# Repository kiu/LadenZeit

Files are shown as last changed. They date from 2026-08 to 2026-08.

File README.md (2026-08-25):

# LadenZeit
LadenZeit - Never miss opening hours again. Minimalist OLED store tracker with rotary control

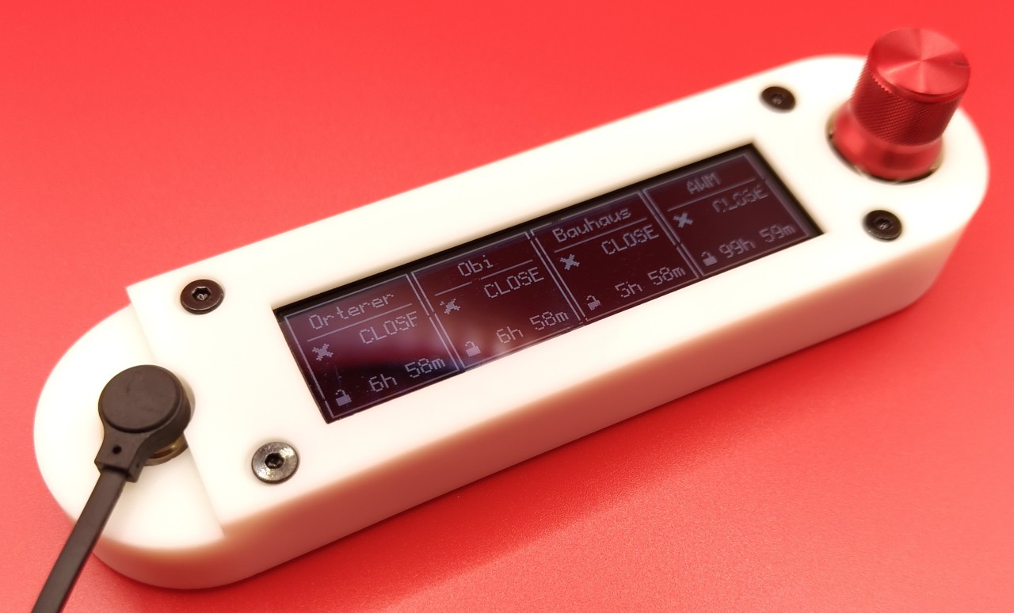
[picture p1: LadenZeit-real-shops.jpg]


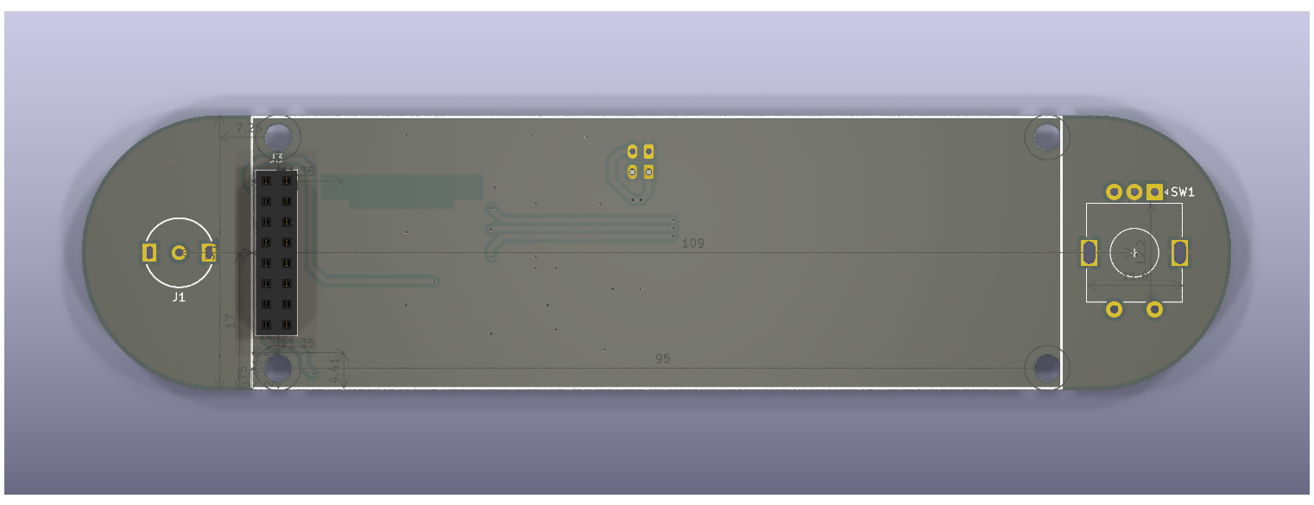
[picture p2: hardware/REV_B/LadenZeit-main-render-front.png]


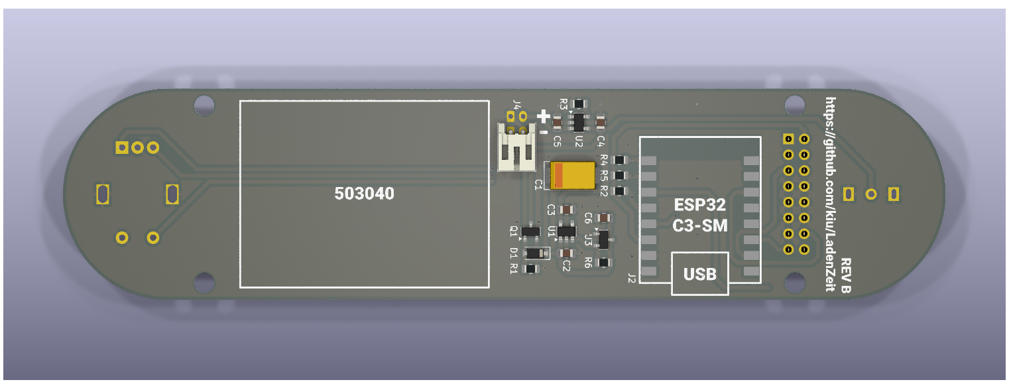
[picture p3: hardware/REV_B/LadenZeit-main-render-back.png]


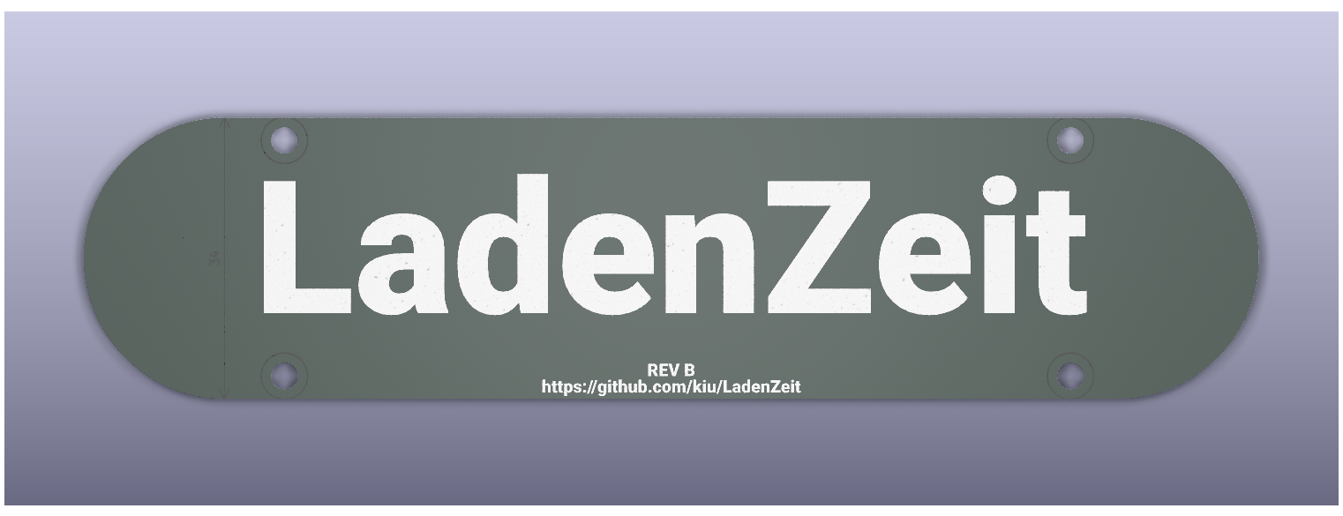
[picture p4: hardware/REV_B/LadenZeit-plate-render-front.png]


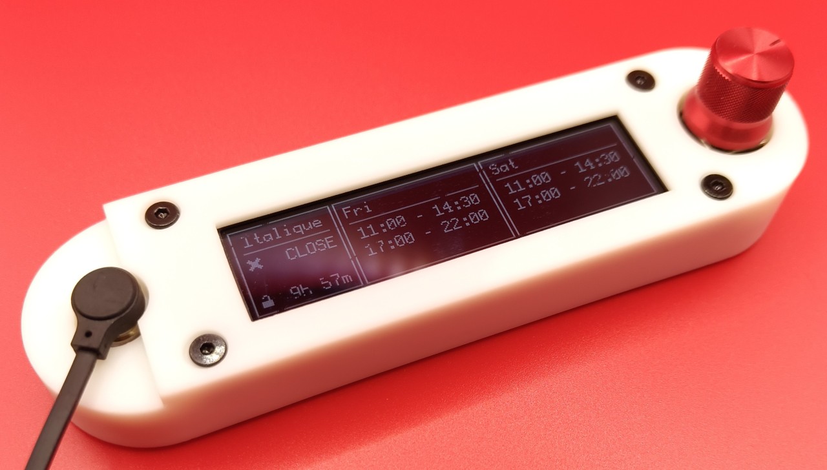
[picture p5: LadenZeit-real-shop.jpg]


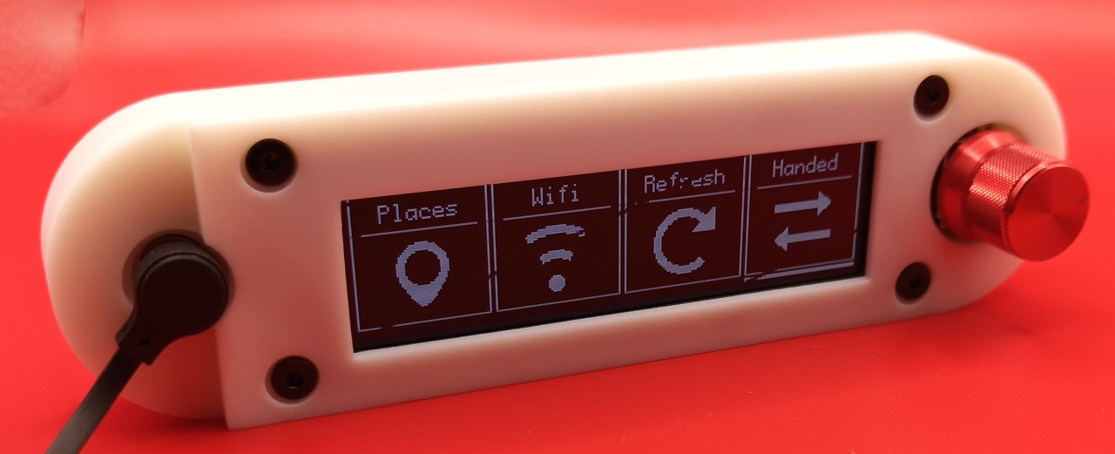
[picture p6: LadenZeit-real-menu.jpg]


## Device

- [main](hardware/REV_B/main/): The main PCB
- [plate](hardware/REV_B/plate/): PCB used as backplate
- [mech](hardware/REV_B/mech/): OpenSCAD case
- [BOM](hardware/REV_B/LadenZeit-bom.pdf): Bill of materials

### Firmware (Arduino IDE)

- [source](firmware/LadenZeit/)
- [UI flow](firmware/ladenzeit-ui-flow.drawio.png)

Arduino IDE config
- Board: [ESP32C3 Dev Module](https://github.com/espressif/arduino-esp32)
- Library: [U8g2](https://github.com/olikraus/u8g2)
- Library: [ESP32Time](https://github.com/fbiego/ESP32Time)
- Config: "USB CDC On Boot: Enabled"
- Config: "CPU Frequency: 80MHz (WiFi)"
- Config: "Partition Scheme: Huge APP (3MB No OTA/1MB SPIFFFS)"

## Server (Java Spring Boot)

- [source](server/LadenZeitServer)
- [single file frontend](server/index.html)
- [service](server/ladenzeit.service)

Inject Google Maps API key via environment.

# License
This project is licensed under the Creative Commons Attribution-NonCommercial 3.0 Unported (CC BY-NC 3.0) license.

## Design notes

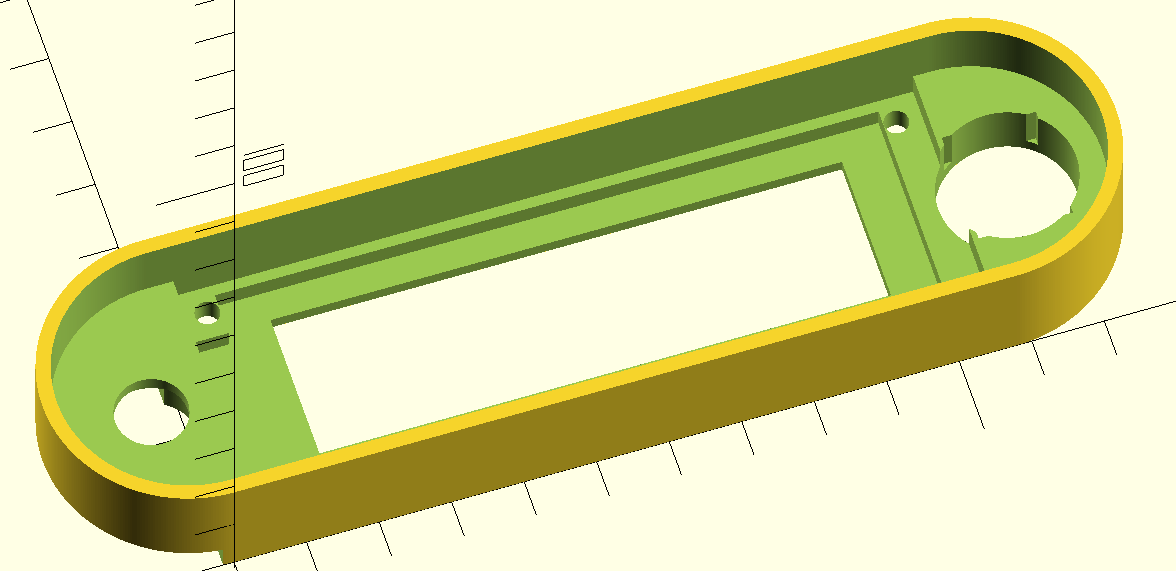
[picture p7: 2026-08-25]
hardware/REV_B/LadenZeit-mech-render.png

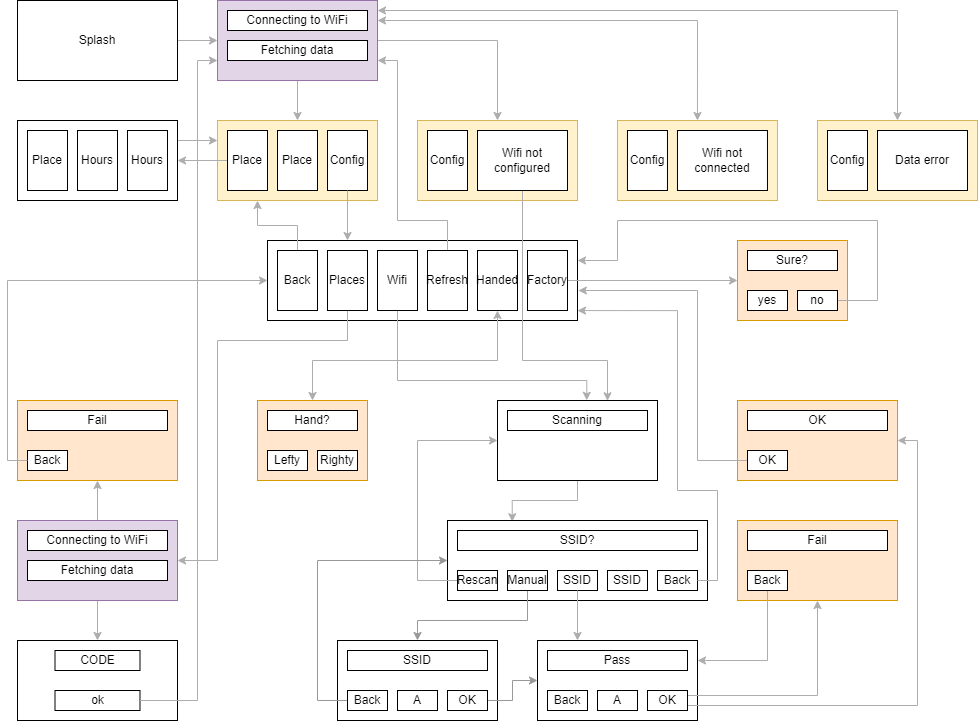
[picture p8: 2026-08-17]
firmware/ladenzeit-ui-flow.drawio.png

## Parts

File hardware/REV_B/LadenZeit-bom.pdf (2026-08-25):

BOM-PCBA

Page 1

Designator | Description | Req | Price | Price (sum) | Provider | ID
MOQ 10
U1 | XC6220B331MR-G | 1 | 0,3579 € | 0,3579 € | | C86534
U2 | MCP73831T-2ACI/OT | 1 | 0,7113 € | 0,7113 € | | C424093
U3 | APX803L-34SA-7 | 1 | 0,1379 € | 0,1379 € | | C2067862
D1 | B5819W SL | 1 | 0,0270 € | 0,0270 € | | C8598
Q1 | DMG2301L-7 | 1 | 0,1080 € | 0,1080 € | | C102619
SW1 | PEC11R-4215F-S0024 | 1 | 1,7730 € | 1,7730 € | | C143790
J1 | USB MG0175 | 1 | 4,9345 € | 4,9345 € | de.aliexpress.com | 1005011921156462
J2 | ESP32-C3 Super Mini | 1 | 2,6590 € | 2,6590 € | de.aliexpress.com | 1005008809016984
J3 | OLED 3.12” 256*64 | 1 | 12,7900 € | 12,7900 € | de.aliexpress.com | 1005003091450549
J4 | B2B-PH-K-S(LF)(SN) | 1 | 0,0317 € | 0,0317 € | | C131337
R1, R3 | 10k 0805 | 2 | 0,0028 € | 0,0056 € | | C2930231
R2, R4, R5, R6 | 47k 0805 | 4 | 0,0095 € | 0,0380 € | | C17713
C1 | 100uF 16V CASE-E-7343 | 1 | 0,5897 € | 0,5897 € | | C554014
C2, C4, C5 | 4.7uF 25V 0805 | 3 | 0,0392 € | 0,1176 € | | C1779
C3 | 47uF 10V 0805 | 1 | 0,1432 € | 0,1432 € | | C19103846
C6 | 100nF 0805 | 1 | 0,0194 € | 0,0194 € | | C49678
- | Dial D-Shaped 15/17*16 | 1 | 1,5250 € | 1,5250 € | de.aliexpress.com | 1005005746658381
- | Li-Ion 503040 | 1 | 4,8750 € | 4,8750 € | de.aliexpress.com | 1005009778420830
- | M3x12 hex screw (ultra flat) | 4 | 0,0430 € | 0,1720 € | de.aliexpress.com | 1005008305312481
- | | 4 | 0,0318 € | 0,1272 € | de.aliexpress.com | 1005008305312481
- | M3x7 spacer | 4 | 0,1590 € | 0,6360 € | de.aliexpress.com | 1005009383384524
- | M3x3 spacer | 4 | 0,0184 € | 0,0736 € | de.aliexpress.com | 1005004322149134

SUM
31,85 €
318,53 €

www.lcsc.com
www.lcsc.com
www.lcsc.com
www.lcsc.com
www.lcsc.com
www.lcsc.com

www.lcsc.com
www.lcsc.com
www.lcsc.com
www.lcsc.com
www.lcsc.com
www.lcsc.com
www.lcsc.com

M3x4 hex screw (ultra flat)

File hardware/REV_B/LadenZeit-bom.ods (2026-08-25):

Designator | Description | Req | Price | Price (sum) | Provider | ID
 |  |  | MOQ | 10
U1 | XC6220B331MR-G | 1 | 0,3579 € | 0,3579 € | www.lcsc.com | C86534
U2 | MCP73831T-2ACI/OT | 1 | 0,7113 € | 0,7113 € | www.lcsc.com | C424093
U3 | APX803L-34SA-7 | 1 | 0,1379 € | 0,1379 € | www.lcsc.com | C2067862
D1 | B5819W SL | 1 | 0,0270 € | 0,0270 € | www.lcsc.com | C8598
Q1 | DMG2301L-7 | 1 | 0,1080 € | 0,1080 € | www.lcsc.com | C102619
SW1 | PEC11R-4215F-S0024 | 1 | 1,7730 € | 1,7730 € | www.lcsc.com | C143790
J1 | USB MG0175 | 1 | 4,9345 € | 4,9345 € | de.aliexpress.com | 1005011921156462
J2 | ESP32-C3 Super Mini | 1 | 2,6590 € | 2,6590 € | de.aliexpress.com | 1005008809016984
J3 | OLED 3.12” 256*64 | 1 | 12,7900 € | 12,7900 € | de.aliexpress.com | 1005003091450549
J4 | B2B-PH-K-S(LF)(SN) | 1 | 0,0317 € | 0,0317 € | www.lcsc.com | C131337
R1, R3 | 10k 0805 | 2 | 0,0028 € | 0,0056 € | www.lcsc.com | C2930231
R2, R4, R5, R6 | 47k 0805 | 4 | 0,0095 € | 0,0380 € | www.lcsc.com | C17713
C1 | 100uF 16V CASE-E-7343 | 1 | 0,5897 € | 0,5897 € | www.lcsc.com | C554014
C2, C4, C5 | 4.7uF 25V 0805 | 3 | 0,0392 € | 0,1176 € | www.lcsc.com | C1779
C3 | 47uF 10V 0805 | 1 | 0,1432 € | 0,1432 € | www.lcsc.com | C19103846
C6 | 100nF 0805 | 1 | 0,0194 € | 0,0194 € | www.lcsc.com | C49678
- | Dial D-Shaped 15/17*16 | 1 | 1,5250 € | 1,5250 € | de.aliexpress.com | 1005005746658381
- | Li-Ion 503040 | 1 | 4,8750 € | 4,8750 € | de.aliexpress.com | 1005009778420830
- | M3x12 hex screw (ultra flat) | 4 | 0,0430 € | 0,1720 € | de.aliexpress.com | 1005008305312481
- | M3x4 hex screw (ultra flat) | 4 | 0,0318 € | 0,1272 € | de.aliexpress.com | 1005008305312481
- | M3x7 spacer | 4 | 0,1590 € | 0,6360 € | de.aliexpress.com | 1005009383384524
- | M3x3 spacer | 4 | 0,0184 € | 0,0736 € | de.aliexpress.com | 1005004322149134
 |  |  |  | SUM
 |  |  |  | 31,85 €
 |  |  |  | 318,53 €

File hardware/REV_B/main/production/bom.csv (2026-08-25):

Designator | Footprint | Quantity | Value | LCSC Part #
C1 | CP_EIA-7343-43_Kemet-X_HandSolder | 1 | 100uF | C554014
C2, C4, C5 | 0805 | 3 | 4.7uF | C1779
C3 | 0805 | 1 | 47uF | C19103846
C6 | 0805 | 1 | 100nF | C49678
D1 | D_SOD-123 | 1 | D_Schottky | C8598
J1 | USB MG0175M | 1 | Conn_01x02
J2 | ESP32-C3-SM-SMT | 1 | Conn_02x08_Odd_Even
J3 | PinSocket_2x08_P2.54mm_Vertical | 1 | Conn_02x08_Odd_Even | C30734
J4 | JST_PH_S2B-PH-K_1x02_P2.00mm_Horizontal-Multi | 1 | Conn_01x02 | C131337
Q1 | SOT-23 | 1 | DMG2301L | C102619
R1, R3 | 0805 | 2 | 10k | C2930231
R2, R4, R5, R6 | 0805 | 4 | 47k | C17713
SW1 | RotaryEncoder_Alps_EC11E-Switch_Vertical_H20mm | 1 | RotaryEncoder | C143790
U1 | SOT-23-5 | 1 | XC6220B331MR | C86534
U2 | SOT-23-5 | 1 | MCP73831-2-OT | C424093
U3 | SOT-23 | 1 | APX803L | C2067862

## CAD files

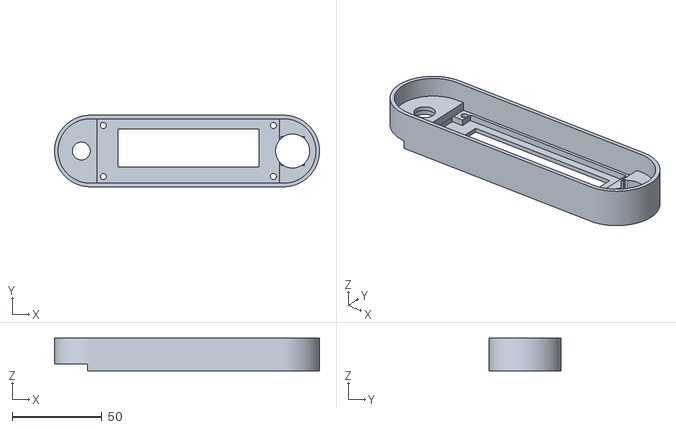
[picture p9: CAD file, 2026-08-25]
hardware/REV_B/mech/LadenZeit.stl
148.0 x 40.0 x 18.4

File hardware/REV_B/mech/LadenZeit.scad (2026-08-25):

$fn = $preview?20:360;
//$fn = $preview?20:60;

pcb_thick = 1;

pcb_width = 108;
pcb_height = 34;

pcb_oled_width = 100;
pcb_oled_height = 33.5;

pcb_oled_spacing = 3;

oled_screen_width = 78.8;
oled_screen_height = 21.18;
oled_screen_thick = 2.8;

oled_screen_x_off = 0.75;
oled_screen_y_off = -1.75;

interact_x = 59;

pcb_holes_x = 95;
pcb_holes_y = 28.5;
pcb_holes_dia = 3.4;

// -------------------------------------------------------

c_pcb_width = pcb_width; // +2 not needed, due to circles having higher diameter due to pcb_height
c_pcb_height = pcb_height + 2;

wall = 2;

// STACKUP
//
// Screw Head   3 / 1.4
// PCB plate    1
// Space        6
// PCB main     1
// Space        3
// PCB OLED     1
// OLED         3
// Wall         2


pcb_off = wall + pcb_oled_spacing + pcb_thick + pcb_oled_spacing;
c_thick = 1.4 + pcb_thick + 6 + pcb_thick + pcb_off;

// -------------------------------------------------------

module pcb() {
    difference() {
        union() {            

            // Main PCB
            translate([0, 0, pcb_thick / 2]) cube ([pcb_width, pcb_height, pcb_thick], center = true);            
            // Left half
            translate([-pcb_width / 2, 0, pcb_thick / 2]) cylinder(h=pcb_thick, d=pcb_height, center = true);            
            // Right half
            translate([ pcb_width / 2, 0, pcb_thick / 2]) cylinder(h=pcb_thick, d=pcb_height, center = true);
            
            // Oled PCB            
            translate([0, 0, pcb_thick + (pcb_oled_spacing / 2 + pcb_thick / 2)]) cube ([pcb_oled_width, pcb_oled_height, pcb_oled_spacing + pcb_thick], center = true);
            
            // Oled Screen
            translate([oled_screen_x_off, oled_screen_y_off, pcb_thick + pcb_oled_spacing + pcb_thick + oled_screen_thick / 2]) cube ([oled_screen_width, oled_screen_height, oled_screen_thick], center = true);
            // Power
            translate([-interact_x, 0, pcb_thick + 3]) cylinder(h=6, d=8, center = true);
            translate([-interact_x, 0, pcb_thick + 6 + 2.5]) cylinder(h=5, d=11, center = true);
            
            // Rotary
            translate([interact_x, 0, pcb_thick + 3]) cube ([12, 14, 6], center = true);
            translate([interact_x, 0, pcb_thick + 10.5]) cylinder(h=21, d=7, center = true);
            translate([interact_x, 0, pcb_thick + 15]) cylinder(h=16, d=17, center = true);
            
            // Plate PCB
            translate([0, 0, pcb_thick / 2 - 9 - pcb_thick]) cube ([pcb_width, pcb_height, pcb_thick], center = true);
            // Left half
            translate([-pcb_width / 2, 0, pcb_thick / 2 - 9 - pcb_thick]) cylinder(h=pcb_thick, d=pcb_height, center = true);            
            // Right half
            translate([ pcb_width / 2, 0, pcb_thick / 2 - 9 - pcb_thick]) cylinder(h=pcb_thick, d=pcb_height, center = true);
        }
        
        // Main Holes
        h = pcb_thick + pcb_oled_spacing + pcb_thick;
        translate([-pcb_holes_x / 2 + oled_screen_x_off, -pcb_holes_y / 2, h / 2]) cylinder(h=h, d=pcb_holes_dia, center = true);
        translate([-pcb_holes_x / 2 + oled_screen_x_off,  pcb_holes_y / 2, h / 2]) cylinder(h=h, d=pcb_holes_dia, center = true);
        translate([ pcb_holes_x / 2 + oled_screen_x_off, -pcb_holes_y / 2, h / 2]) cylinder(h=h, d=pcb_holes_dia, center = true);
        translate([ pcb_holes_x / 2 + oled_screen_x_off,  pcb_holes_y / 2, h / 2]) cylinder(h=h, d=pcb_holes_dia, center = true);

        // Plate Holes
        hbot = pcb_thick + 9 + pcb_thick;
        translate([-pcb_holes_x / 2 + oled_screen_x_off, -pcb_holes_y / 2, -hbot / 2]) cylinder(h=hbot, d=pcb_holes_dia, center = true);
        translate([-pcb_holes_x / 2 + oled_screen_x_off,  pcb_holes_y / 2, -hbot / 2]) cylinder(h=hbot, d=pcb_holes_dia, center = true);
        translate([ pcb_holes_x / 2 + oled_screen_x_off, -pcb_holes_y / 2, -hbot / 2]) cylinder(h=hbot, d=pcb_holes_dia, center = true);
        translate([ pcb_holes_x / 2 + oled_screen_x_off,  pcb_holes_y / 2, -hbot / 2]) cylinder(h=hbot, d=pcb_holes_dia, center = true);
    }
}

module case() {
    height_w2 = wall + c_pcb_height + wall;
    
    difference() {
        union() {            
            // Main PCB
            translate([0, 0, 0]) cube ([c_pcb_width, height_w2, c_thick]);            
            // Left half
            translate([0           , (height_w2)/ 2, 0]) cylinder(h=c_thick, d=height_w2);
            // Right half
            translate([ c_pcb_width, (height_w2)/ 2, 0]) cylinder(h=c_thick, d=height_w2);
        }
  
        translate([c_pcb_width / 2, height_w2/ 2, 0]) {
            // Rotary
            translate([interact_x, 0, 0]) cylinder(h=c_thick, d=19);  
            translate([interact_x - 13/2, -16/2, 2]) cube ([13, 16, 7]);
            
            // Power
            translate([-interact_x, 0, 0]) cylinder(h=pcb_off, d=10);            
            translate([-interact_x, 0, 0]) cylinder(h=7, d=13);
            translate([-interact_x + 7/2 - 100, -height_w2 / 2, 0]) cube ([100, height_w2, 4]);
                       
            // Main Holes            
            translate([-pcb_holes_x / 2 + oled_screen_x_off, -pcb_holes_y / 2, 0]) cylinder(h=c_thick, d=pcb_holes_dia);
            translate([-pcb_holes_x / 2 + oled_screen_x_off,  pcb_holes_y / 2, 0]) cylinder(h=c_thick, d=pcb_holes_dia);
            translate([ pcb_holes_x / 2 + oled_screen_x_off, -pcb_holes_y / 2, 0]) cylinder(h=c_thick, d=pcb_holes_dia);
            translate([ pcb_holes_x / 2 + oled_screen_x_off,  pcb_holes_y / 2, 0]) cylinder(h=c_thick, d=pcb_holes_dia);

            // Main Head // 6.4
            translate([-pcb_holes_x / 2 + oled_screen_x_off, -pcb_holes_y / 2, 0]) cylinder(h=1.2, d=7);
            translate([-pcb_holes_x / 2 + oled_screen_x_off,  pcb_holes_y / 2, 0]) cylinder(h=1.2, d=7);
            translate([ pcb_holes_x / 2 + oled_screen_x_off, -pcb_holes_y / 2, 0]) cylinder(h=1.2, d=7);
            translate([ pcb_holes_x / 2 + oled_screen_x_off,  pcb_holes_y / 2, 0]) cylinder(h=1.2, d=7);

            // OLED Window
            translate([-oled_screen_width / 2 + oled_screen_x_off, -oled_screen_height / 2 - oled_screen_y_off, 0]) cube ([oled_screen_width, oled_screen_height, c_thick]);
            // OLED
            translate([-91.5 / 2 + oled_screen_x_off, -33 / 2, wall]) cube ([91.5, 33, pcb_oled_spacing]);            
            // OLED connector
            translate([-7 / 2 - pcb_holes_x / 2, -21 / 2, wall]) cube ([7, 21, pcb_oled_spacing]);
            // OLED PCB
            translate([-(1 + pcb_oled_width + 1) / 2 + 0.75, -c_pcb_height / 2, wall + pcb_oled_spacing]) cube ([1 + pcb_oled_width + 1, c_pcb_height, c_thick]);
           
            // MAIN PCB
            translate([-c_pcb_width / 2, -c_pcb_height / 2, pcb_off]) cube ([c_pcb_width, c_pcb_height, c_thick]);
            // Left half
            translate([-c_pcb_width / 2, 0, pcb_off]) cylinder(h=c_thick, d=c_pcb_height);
            // Right half
            translate([ c_pcb_width / 2, 0, pcb_off]) cylinder(h=c_thick, d=c_pcb_height);            
        }
   }
}

color([0,0,1]) case();

//color([1,0,0]) translate([c_pcb_width / 2, (wall + c_pcb_height + wall)/ 2, c_thick/2 + 2 - 3]) rotate ([180, 0, 0]) pcb();

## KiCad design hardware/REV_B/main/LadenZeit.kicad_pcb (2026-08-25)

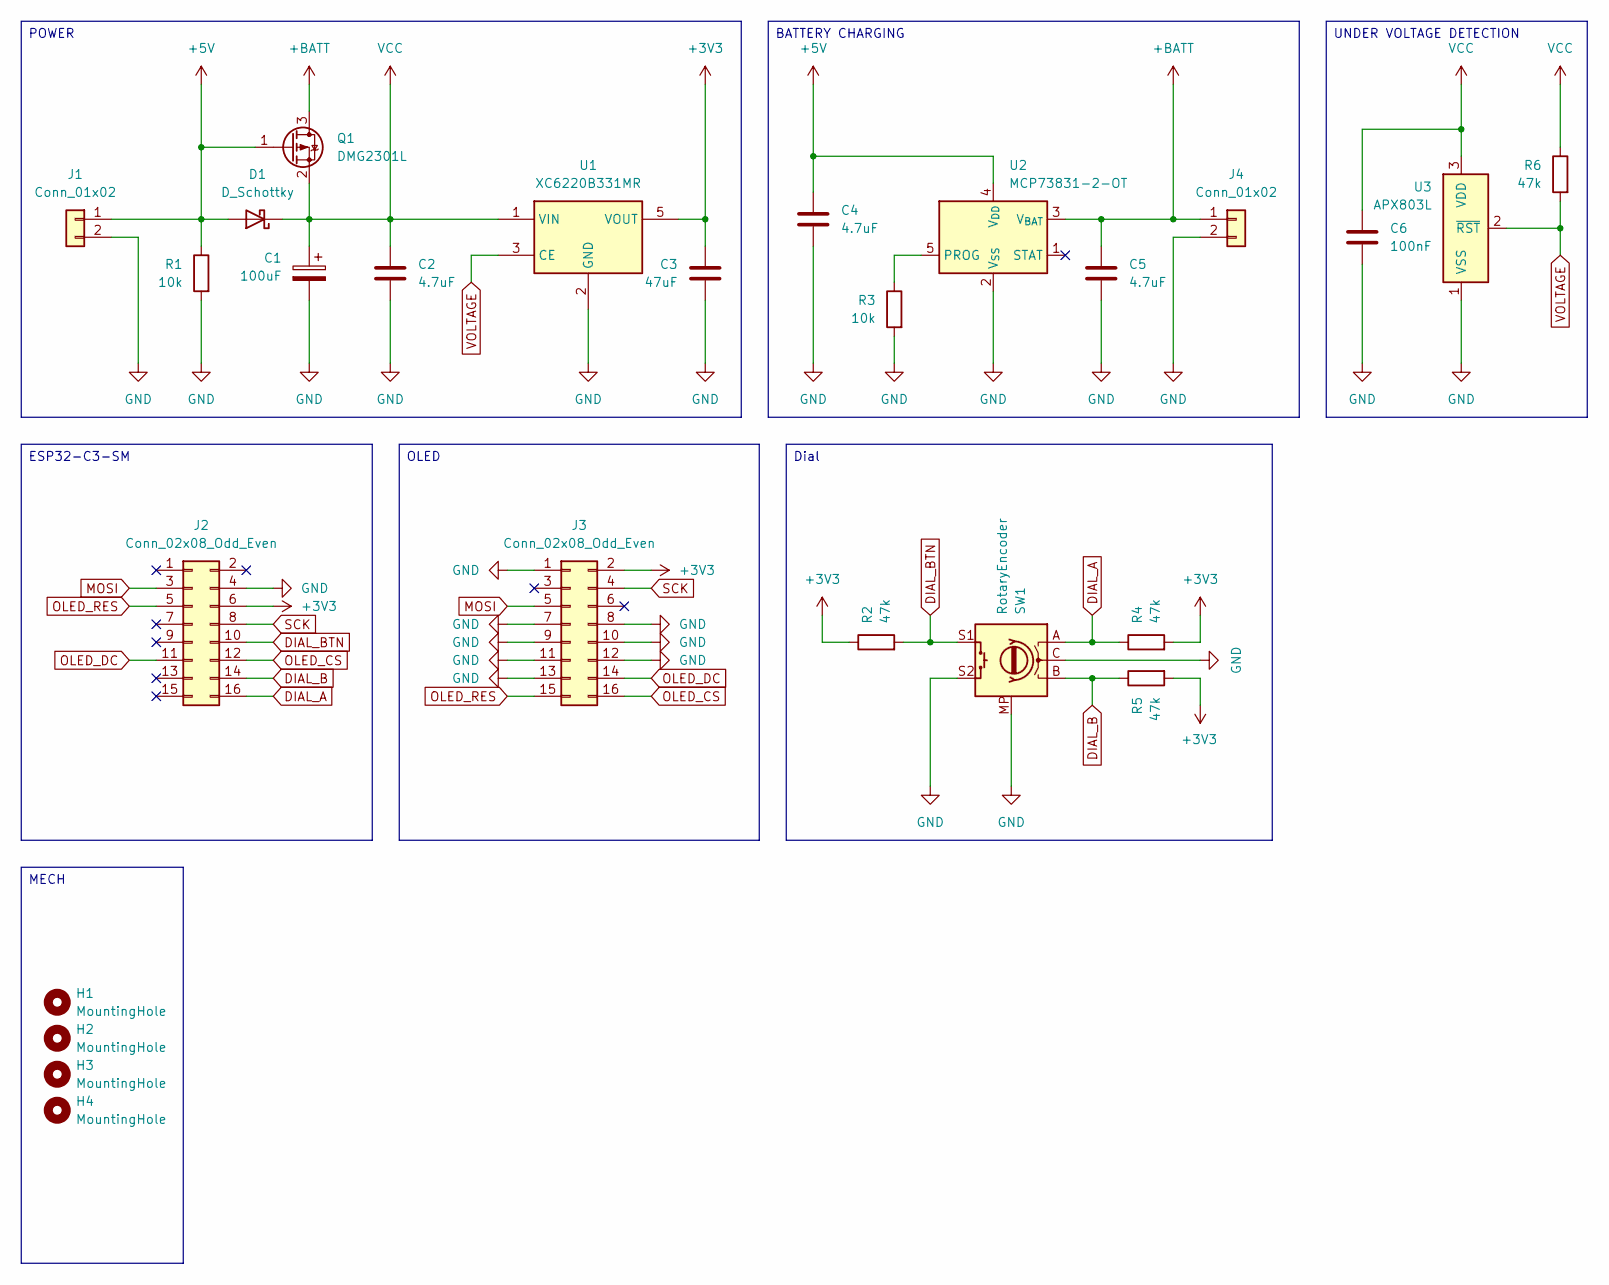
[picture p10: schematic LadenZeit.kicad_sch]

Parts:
C1: 100uF; CP_EIA-7343-43_Kemet-X_HandSolder; LCSC C554014
C2, C4, C5: 4.7uF; C_0805_2012Metric; LCSC C1779
C3: 47uF; C_0805_2012Metric; LCSC C19103846
C6: 100nF; C_0805_2012Metric; LCSC C49678
D1: D_Schottky; D_SOD-123; LCSC C8598
H1, H2, H3, H4: MountingHole; MountingHole_3.2mm_M3_DIN965
J1: Conn_01x02; USB MG0175M
J2: Conn_02x08_Odd_Even; ESP32-C3-SM-SMT
J3: Conn_02x08_Odd_Even; PinSocket_2x08_P2.54mm_Vertical
J4: Conn_01x02; JST_PH_S2B-PH-K_1x02_P2.00mm_Horizontal-Multi; LCSC C131337
Q1: DMG2301L; SOT-23; LCSC C102619
R1, R3: 10k; R_0805_2012Metric; LCSC C2930231
R2, R4, R5, R6: 47k; R_0805_2012Metric; LCSC C17713
SW1: RotaryEncoder; RotaryEncoder_Alps_EC11E-Switch_Vertical_H20mm; LCSC C143790
U1: XC6220B331MR; SOT-23-5; LCSC C86534
U2: MCP73831-2-OT; SOT-23-5; LCSC C424093
U3: APX803L; SOT-23; LCSC C2067862

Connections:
+3V3: C3.1, J2.6, J3.2, R2.1, R4.2, R5.2, U1.5 (VOUT)
+5V: C4.1, D1.2 (A), J1.1, Q1.1 (G), R1.1, U2.4 (V_{DD})
+BATT: C5.1, J4.1, Q1.3 (D), U2.3 (V_{BAT})
DIAL_A: J2.16, R4.1, SW1.A
DIAL_B: J2.14, R5.1, SW1.B
DIAL_BTN: J2.10, R2.2, SW1.S1
GND: C1.2, C2.2, C3.2, C4.2, C5.2, C6.2, J1.2, J2.4, J3.1, J3.7, J3.8, J3.9, J3.10, J3.11, J3.12, J3.13, J4.2, R1.2, R3.2, SW1.C, SW1.MP, SW1.S2, U1.2 (GND), U2.2 (V_{SS}), U3.1 (VSS)
MOSI: J2.3, J3.5
unnamed: R3.1, U2.5 (PROG)
OLED_CS: J2.12, J3.16
OLED_DC: J2.11, J3.14
OLED_RES: J2.5, J3.15
SCK: J2.8, J3.4
VCC: C1.1, C2.1, C6.1, D1.1 (K), Q1.2 (S), R6.1, U1.1 (VIN), U3.3 (VDD)
VOLTAGE: R6.2, U1.3 (CE), U3.2 (~RST)

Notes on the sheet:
UNDER VOLTAGE DETECTION
ESP32-C3-SM
POWER
BATTERY CHARGING
MECH
Dial
OLED

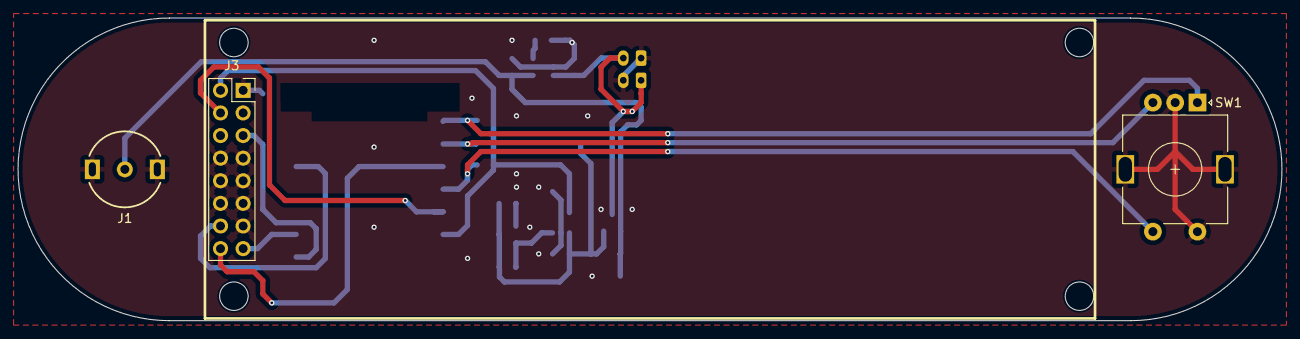
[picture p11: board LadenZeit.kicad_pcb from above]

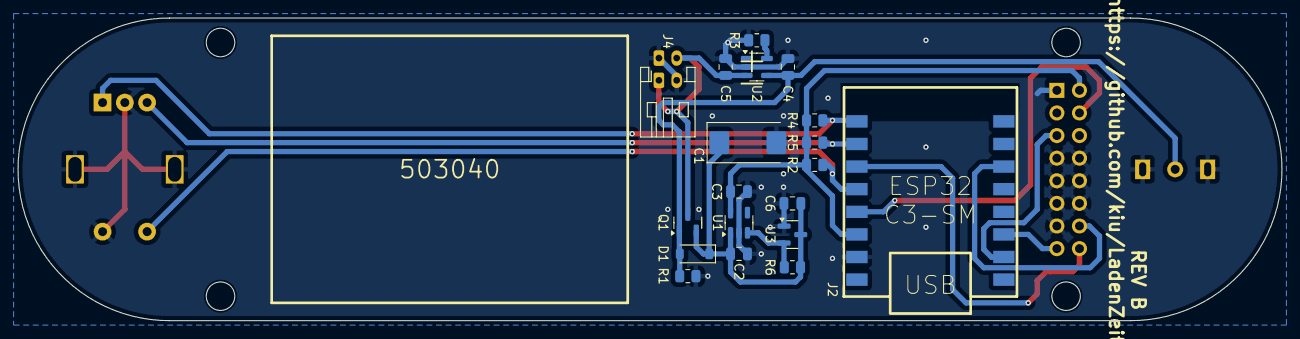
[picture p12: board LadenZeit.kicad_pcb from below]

Board: 2 copper layers, 142.0 x 34.0 mm, 26 parts (19 on the bottom side), 15 nets.

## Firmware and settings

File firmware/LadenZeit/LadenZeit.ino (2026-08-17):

#include "LadenZeit.h"

#include "lz_config.h"

#include <Preferences.h>
#include <nvs_flash.h>
#include <esp_sleep.h>

#include "lz_dial.h"
#include "lz_network.h"
#include "lz_oled.h"
#include "lz_places.h"
#include "lz_time.h"

const char* appName = "LadenZeit";
const char* appVersion = "v0.0.1";
const char* appRev = "REV B";

volatile bool oledUpdate = true;

AppState state = STATE_INIT;
AppState stateNext = STATE_INIT;
AppState statePrev = STATE_INIT;
AppState stateSsidPrev = STATE_INIT;

uint8_t mainNavCount = 0;
uint8_t mainNavPerPage = 0;
uint8_t mainNavStart = 0;
uint8_t mainNavSelected = 0;

uint8_t mainNavStartLast = 0;
uint8_t mainNavSelectedLast = 0;

// Place whose detail screen is shown, captured when it's picked from the list
// (the detail state reuses the nav window for its day columns).
uint8_t mainPlaceSelected = 0;

String mainPass = "";
String mainSsid = "";

const char* btnsHanded[] = { "Lefty", "Righty" };
const char* btnsFactory[] = { "Back", "Reset" };
const char* btnsMenuPlaces[] = { "Back", "Retry" };
const char* btnsOk[] = { "OK" };
const char* btnsWifiFail[] = { "Back", "Retry" };

NetworkState mainNetworkStatePlaces = NETWORK_OK;
bool mainNetworkPlacesForceUpdate = false;

bool startFresh = true;

time_t mainActionLast;

// One row per screen in the STATES[] dispatch table (defined lower down, after
// the handler functions it points at). See the STATE MACHINE section for how the
// loop* passes use these three handlers.
struct StateDef {
  void (*onEnter)();
  void (*onButton)();
  void (*onRender)();
};

// --------------------------------------------------------------- MAIN

void mainOledUpdate() {
  oledUpdate = true;
}

void mainFactoryReset() {
  oledBufferClear();
  oledBufferSend();

  nvs_flash_erase();  // Erases the entire NVS partition
  nvs_flash_init();   // Re-initializes it for fresh use

  ESP.restart();
}

// --------------------------------------------------------------- NETWORK

// Runs a blocking connect + request (called from onEnter handlers), so loop()
// is parked for the duration. Progress is pushed straight to the panel via
// oledShowConnectionStatus() rather than the loopOled() render phase — the one
// intentional exception to "rendering goes through onRender". Deliberately kept
// synchronous: the device has nothing else to do while a fetch is in flight.
NetworkState mainNetwork(NetworkState (*func)()) {
  oledShowConnectionStatus(1, 0);

  NetworkState result;

  result = wifiConnect();
  if (result == NETWORK_OK) {
    oledShowConnectionStatus(2, 0);
  } else {
    oledShowConnectionStatus(3, 0);
  }

  if (result == NETWORK_OK) {
    oledShowConnectionStatus(2, 1);
    result = func();
    if (result == NETWORK_OK) {
      oledShowConnectionStatus(2, 2);
    } else {
      oledShowConnectionStatus(2, 3);
    }
    wifiDisconnect();
  }

  return result;
}

NetworkState mainNetworkPlacesDownload() {
  bool run = false;

  run |= mainNetworkPlacesForceUpdate;
  run |= timeCacheExpired();
  run |= !placesValid();  // no valid data (e.g. last refresh rejected) — must re-fetch

  mainNetworkPlacesForceUpdate = false;

  if (!run) {
    return NETWORK_OK;
  }

  NetworkState result = mainNetwork(httpDownloadPlaces);
  if (result == NETWORK_OK) {
    placesUpdateTime();
    placesDebug();
    timeCacheInit();
  }
  return result;
}

NetworkState mainNetworkPlacesConfiguration() {
  return mainNetwork(httpEnableConfig);
}

// --------------------------------------------------------------- NAVIGATION

// Absolute index of the current selection within the nav window.
uint8_t mainNavIndex() {
  return mainNavStart + mainNavSelected;
}

// Single-page nav window (perPage == count, no scrolling): the common shape for
// confirm dialogs. Sets the selected item; start is reset to 0.
void mainNavSet(uint8_t count, uint8_t selected) {
  mainNavStart = 0;
  mainNavCount = count;
  mainNavPerPage = count;
  mainNavSelected = selected;
}

bool mainNavDial(int8_t diff) {
  //LOG("A Diff: %d C:%d S:%d P:%d S:%d\n", diff, mainNavCount, mainNavStart, mainNavPerPage, mainNavSelected);

  if (mainNavCount == 0) {
    return false;
  }
  if (mainNavCount == 1) {
    return false;
  }

  while (diff > 0) {
    diff--;
    if (mainNavSelected < mainNavPerPage - 1) {
      if (mainNavSelected < mainNavCount - 1) {
        mainNavSelected++;
      }
    } else {
      if (mainNavStart + mainNavPerPage < mainNavCount) {
        mainNavStart++;
      }
    }
  }

  while (diff < 0) {
    diff++;
    if (mainNavSelected > 0) {
      mainNavSelected--;
    } else {
      if (mainNavStart > 0) {
        mainNavStart--;
      }
    }
  }

  //LOG("B Diff: %d C:%d S:%d P:%d S:%d\n", diff, mainNavCount, mainNavStart, mainNavPerPage, mainNavSelected);

  return true;
}

// --------------------------------------------------------------- STATE MACHINE
//
// Each screen is one row in the STATES[] table below, holding up to three
// handlers dispatched by the generic loop* functions:
//   onEnter()  - runs once on transition into the state; sets nav counts /
//                side effects, and may set stateNext (for action-only states).
//   onButton() - runs on a dial button press.
//   onRender() - redraws the screen (called when oledUpdate is set).
// A null handler means "nothing to do"; loop* logs an undefined-state notice
// when a state is reached with no handler for that phase (matching the old
// switch defaults). STATE_MENU_PLACES keeps an empty (non-null) render so it
// stays silent, as before. StateDef itself is declared up top with the globals.

// ---- onEnter handlers ----

void stPlacesListEnter() {
  stateSsidPrev = STATE_PLACES_LIST;
  mainNetworkStatePlaces = mainNetworkPlacesDownload();
  mainNavCount = placesCount() + 1;
  mainNavPerPage = PLACES_PER_PAGE;
  if (mainNetworkStatePlaces != NETWORK_OK) {
    stateNext = STATE_PLACES_LIST_ERROR;
  }
}

void stPlacesErrorEnter() {
  mainNavSet(2, 1);
}

void stPlacesDetailEnter() {
  // Open on today's column. timeDayGet() is 0=Sunday; the detail columns are
  // Monday-first, so today's position is (day + 6) % 7.
  uint8_t pos = (timeDayGet() + DAYS_PER_WEEK - 1) % DAYS_PER_WEEK;
  mainNavCount = DAYS_PER_WEEK;
  mainNavPerPage = DETAIL_DAYS_PER_PAGE;
  if (pos + DETAIL_DAYS_PER_PAGE <= DAYS_PER_WEEK) {
    mainNavStart = pos;
    mainNavSelected = 0;
  } else {
    mainNavStart = DAYS_PER_WEEK - DETAIL_DAYS_PER_PAGE;
    mainNavSelected = pos - mainNavStart;
  }
}

void stMenuEnter() {
  mainNavCount = MENU_COUNT;
  mainNavPerPage = MENU_PER_PAGE;
  stateSsidPrev = STATE_MENU;
}

void stMenuPlacesEnter() {
  mainNavCount = 0;
  mainNavPerPage = 0;
  NetworkState result = mainNetworkPlacesConfiguration();
  if (result == NETWORK_OK) {
    stateNext = STATE_MENU_PLACES_CODE;
  } else {
    stateNext = STATE_MENU_PLACES_FAIL;
  }
}

void stMenuPlacesCodeEnter() {
  mainNavSet(1, 0);
}

void stMenuPlacesFailEnter() {
  mainNavSet(2, 1);
}

void stMenuWifiSsidEnter() {
  mainNavStart = 0;
  mainNavCount = 0;
  mainNavPerPage = 0;
  mainNavSelected = 0;
  stateNext = STATE_MENU_WIFI_SSID_RES;
}

void stMenuWifiSsidResEnter() {
  mainNavStart = 0;
  mainNavSelected = 0;
  // Scan only when reached via the scan trigger (main menu, error recovery, or
  // Rescan). Returning from the pass/manual screens reuses the cached results,
  // so navigating back no longer forces a fresh blocking scan every time.
  if (statePrev == STATE_MENU_WIFI_SSID) {
    wifiScan();
  }
  // scanned SSIDs + 3 control rows: Back (top), Rescan and Manual (bottom).
  mainNavCount = wifiScanLen() + 3;
  mainNavPerPage = WIFI_SSID_PER_PAGE;
}

void stMenuWifiSsidManualEnter() {
  mainNavCount = wifiPassSlotCount();
  mainNavPerPage = WIFI_PASS_PER_PAGE;
  if (startFresh) {
    startFresh = false;
    mainSsid = "";
  }
}

void stMenuWifiPassEnter() {
  mainNavCount = wifiPassSlotCount();
  mainNavPerPage = WIFI_PASS_PER_PAGE;
  if (startFresh) {
    startFresh = false;
    mainPass = "";
  }
}

void stMenuWifiTestEnter() {
  stateNext = STATE_MENU_WIFI_TEST_RUN;
}

void stMenuWifiTestRunEnter() {
  if (wifiConnectAndStore(mainSsid, mainPass) == NETWORK_OK) {
    stateNext = STATE_MENU_WIFI_TEST_OK;
  } else {
    stateNext = STATE_MENU_WIFI_TEST_FAIL;
  }
}

void stMenuWifiTestOkEnter() {
  mainNavSet(1, 0);
}

void stMenuWifiTestFailEnter() {
  mainNavSet(2, 0);
}

void stMenuHandedEnter() {
  mainNavSet(2, !oledFlipGet());
}

void stMenuFactoryEnter() {
  mainNavSet(2, 0);
}

// ---- onButton handlers ----

void stPlacesListButton() {
  if (mainNavIndex() == mainNavCount - 1) {
    stateNext = STATE_MENU;
  } else {
    mainPlaceSelected = mainNavIndex();
    stateNext = STATE_PLACES_DETAIL;
  }
}

void stPlacesErrorButton() {
  switch (mainNavIndex()) {
    case 0:
      stateNext = STATE_MENU;
      break;

    case 1:
      if (mainNetworkStatePlaces == NETWORK_ERROR_CONFIGURATION) {
        stateNext = STATE_MENU_WIFI_SSID;
      } else if (mainNetworkStatePlaces == NETWORK_ERROR_CONNECTION) {
        stateNext = STATE_PLACES_LIST;
      } else if (mainNetworkStatePlaces == NETWORK_ERROR_DATA) {
        stateNext = STATE_PLACES_LIST;
      } else {
        LOG("main: undefined error state for button press in network error (%d)\n", mainNavIndex());
      }
      break;

    default:
      LOG("main: undefined menu selected for button press in network error (%d)\n", mainNavIndex());
      break;
  }
}

void stPlacesDetailButton() {
  stateNext = STATE_PLACES_LIST;
}

void stMenuButton() {
  switch (mainNavIndex()) {
    case MENU_BACK:
      stateNext = STATE_PLACES_LIST;
      break;

    case MENU_PLACES:
      stateNext = STATE_MENU_PLACES;
      break;

    case MENU_WIFI:
      stateNext = STATE_MENU_WIFI_SSID;
      break;

    case MENU_REFRESH:
      mainNetworkPlacesForceUpdate = true;
      stateNext = STATE_PLACES_LIST;
      break;

    case MENU_HANDED:
      stateNext = STATE_MENU_HANDED;
      break;

    case MENU_FACTORY:
      stateNext = STATE_MENU_FACTORY;
      break;

    default:
      LOG("main: undefined menu selected for button press (%d)\n", mainNavIndex());
      break;
  }
}

void stMenuPlacesCodeButton() {
  stateNext = STATE_PLACES_LIST;
  mainNetworkPlacesForceUpdate = true;
}

void stMenuPlacesFailButton() {
  if (mainNavSelected == 0) {
    stateNext = STATE_MENU;
  } else {
    stateNext = STATE_MENU_PLACES;
  }
}

void stMenuWifiSsidResButton() {
  uint8_t idx = mainNavIndex();
  if (idx == 0) {
    stateNext = stateSsidPrev;
  } else if (idx == wifiScanLen() + 1) {
    stateNext = STATE_MENU_WIFI_SSID;
  } else if (idx == wifiScanLen() + 2) {
    startFresh = true;
    stateNext = STATE_MENU_WIFI_SSID_MANUAL;
  } else {
    startFresh = true;
    stateNext = STATE_MENU_WIFI_PASS;
    mainSsid = wifiScanItems()[idx - 1];
    LOG("wifi: Selected SSID (%02d) %s\n", idx, mainSsid.c_str());
  }
}

void stMenuWifiSsidManualButton() {
  char c;
  switch (wifiPassSlotKey(mainNavIndex(), &c)) {
    case WIFI_PASS_KEY_BACK:
      stateNext = STATE_MENU_WIFI_SSID_RES;  // cached list, no re-scan
      break;

    case WIFI_PASS_KEY_OK:
      startFresh = true;  // clear the password field on entry
      stateNext = STATE_MENU_WIFI_PASS;
      break;

    case WIFI_PASS_KEY_DEL:
      oledUpdate = true;
      if (mainSsid.length() > 0) {
        mainSsid = mainSsid.substring(0, mainSsid.length() - 1);
      }
      break;

    case WIFI_PASS_KEY_CHAR:
      if (mainSsid.length() < WIFI_SSID_LEN) {
        oledUpdate = true;
        mainSsid += c;
      }
      break;
  }
}

void stMenuWifiPassButton() {
  char c;
  switch (wifiPassSlotKey(mainNavIndex(), &c)) {
    case WIFI_PASS_KEY_BACK:
      stateNext = STATE_MENU_WIFI_SSID_RES;  // cached list, no re-scan
      break;

    case WIFI_PASS_KEY_OK:
      stateNext = STATE_MENU_WIFI_TEST;
      break;

    case WIFI_PASS_KEY_DEL:
      oledUpdate = true;
      if (mainPass.length() > 0) {
        mainPass = mainPass.substring(0, mainPass.length() - 1);
      }
      break;

    case WIFI_PASS_KEY_CHAR:
      if (mainPass.length() < WIFI_PASS_MAX_LEN) {
        oledUpdate = true;
        mainPass += c;
      }
      break;
  }
}

void stMenuWifiTestOkButton() {
  switch (mainNavIndex()) {
    case 0:
      stateNext = stateSsidPrev;
      break;

    default:
      LOG("main: undefined menu selected for button press in wifi test ok (%d)\n", mainNavIndex());
      break;
  }
}

void stMenuWifiTestFailButton() {
  switch (mainNavIndex()) {
    case 0:
      stateNext = STATE_MENU_WIFI_PASS;
      break;

    case 1:
      stateNext = STATE_MENU_WIFI_TEST;
      break;

    default:
      LOG("main: undefined menu selected for button press in wifi test fail (%d)\n", mainNavIndex());
      break;
  }
}

void stMenuHandedButton() {
  stateNext = STATE_MENU;
  switch (mainNavIndex()) {
    case 0:
      oledFlipSet(true);
      break;

    case 1:
      oledFlipSet(false);
      break;

    default:
      LOG("main: undefined menu selected for button press in handed (%d)\n", mainNavIndex());
      break;
  }
}

void stMenuFactoryButton() {
  switch (mainNavIndex()) {
    case 0:
      stateNext = STATE_MENU;
      break;

    case 1:
      mainFactoryReset();
      break;

    default:
      LOG("main: undefined menu selected for button press in factory (%d)\n", mainNavIndex());
      break;
  }
}

// ---- onRender handlers ----

void stPlacesListRender() {
  oledShowPlacesList(mainNavStart, (mainNavCount > mainNavStart + PLACES_PER_PAGE) ? mainNavPerPage : mainNavCount - mainNavStart, mainNavSelected);
}

void stPlacesErrorRender() {
  if (mainNetworkStatePlaces == NETWORK_ERROR_CONFIGURATION) {
    oledShowPlacesListError("WiFi connection not setup", "Select to configure", mainNavIndex());
  }
  if (mainNetworkStatePlaces == NETWORK_ERROR_CONNECTION) {
    oledShowPlacesListError("WiFi connection failed", "Select to retry", mainNavIndex());
  }
  if (mainNetworkStatePlaces == NETWORK_ERROR_DATA) {
    oledShowPlacesListError("Data transmission failed", "Select to retry", mainNavIndex());
  }
}

void stPlacesDetailRender() {
  oledShowPlacesDetail(mainPlaceSelected, mainNavStart, mainNavSelected);
}

void stMenuRender() {
  oledShowMenu(mainNavStart, mainNavSelected);
}

void stMenuPlacesRender() {
  // intentionally blank: transient config state draws nothing (was an empty
  // switch case; kept non-null so it stays silent instead of logging undefined)
}

void stMenuPlacesCodeRender() {
  char code[24];
  snprintf(code, sizeof code, "Code: %s", httpPasscodeHuman.c_str());
  oledShowDialog("ladenzeit.nakamura-labs.com", code, 1, btnsOk, mainNavSelected);
}

void stMenuPlacesFailRender() {
  oledShowDialog("Network Error", "Failed to enable web interface", 2, btnsMenuPlaces, mainNavSelected);
}

void stMenuWifiSsidRender() {
  oledShowDialog("WiFi Scanning", "Please wait ...", 0, NULL, 0);
}

void stMenuWifiSsidResRender() {
  oledShowWifiSsid(mainNavStart, mainNavSelected);
}

void stMenuWifiSsidManualRender() {
  oledShowWifiSsidManual(mainSsid.c_str(), mainNavStart, mainNavSelected);
}

void stMenuWifiPassRender() {
  oledShowWifiPass(mainSsid.c_str(), mainPass.c_str(), mainNavStart, mainNavSelected);
}

void stMenuWifiTestRender() {
  oledShowDialog("WiFi Connection", "Trying connection", 0, NULL, 0);
}

void stMenuWifiTestOkRender() {
  oledShowDialog("WiFi Connection", "Connection OK", 1, btnsOk, 0);
}

void stMenuWifiTestFailRender() {
  oledShowDialog("WiFi Connection", "Connection failed", 2, btnsWifiFail, mainNavSelected);
}

void stMenuHandedRender() {
  oledShowDialog("Handedness", "Set your main hand", 2, btnsHanded, mainNavSelected);
}

void stMenuFactoryRender() {
  oledShowDialog("Factory Reset", "Are you sure?", 2, btnsFactory, mainNavSelected);
}

// ---- dispatch table ----
// Positional, one row per AppState. Order MUST match the enum in LadenZeit.h;
// the static_assert below guards the row count (not the ordering, so keep the
// name comments in sync). A field left nullptr means "no handler for that phase".

static const StateDef STATES[STATE_COUNT] = {
  /* STATE_INIT                */ { nullptr, nullptr, nullptr },
  /* STATE_PLACES_LIST         */ { stPlacesListEnter, stPlacesListButton, stPlacesListRender },
  /* STATE_PLACES_LIST_ERROR   */ { stPlacesErrorEnter, stPlacesErrorButton, stPlacesErrorRender },
  /* STATE_PLACES_DETAIL       */ { stPlacesDetailEnter, stPlacesDetailButton, stPlacesDetailRender },
  /* STATE_MENU                */ { stMenuEnter, stMenuButton, stMenuRender },
  /* STATE_MENU_PLACES         */ { stMenuPlacesEnter, nullptr, stMenuPlacesRender },
  /* STATE_MENU_PLACES_FAIL    */ { stMenuPlacesFailEnter, stMenuPlacesFailButton, stMenuPlacesFailRender },
  /* STATE_MENU_PLACES_CODE    */ { stMenuPlacesCodeEnter, stMenuPlacesCodeButton, stMenuPlacesCodeRender },
  /* STATE_MENU_WIFI_SSID      */ { stMenuWifiSsidEnter, nullptr, stMenuWifiSsidRender },
  /* STATE_MENU_WIFI_SSID_RES  */ { stMenuWifiSsidResEnter, stMenuWifiSsidResButton, stMenuWifiSsidResRender },
  /* STATE_MENU_WIFI_SSID_MANUAL */ { stMenuWifiSsidManualEnter, stMenuWifiSsidManualButton, stMenuWifiSsidManualRender },
  /* STATE_MENU_WIFI_PASS      */ { stMenuWifiPassEnter, stMenuWifiPassButton, stMenuWifiPassRender },
  /* STATE_MENU_WIFI_TEST      */ { stMenuWifiTestEnter, nullptr, stMenuWifiTestRender },
  /* STATE_MENU_WIFI_TEST_RUN  */ { stMenuWifiTestRunEnter, nullptr, nullptr },
  /* STATE_MENU_WIFI_TEST_OK   */ { stMenuWifiTestOkEnter, stMenuWifiTestOkButton, stMenuWifiTestOkRender },
  /* STATE_MENU_WIFI_TEST_FAIL */ { stMenuWifiTestFailEnter, stMenuWifiTestFailButton, stMenuWifiTestFailRender },
  /* STATE_MENU_HANDED         */ { stMenuHandedEnter, stMenuHandedButton, stMenuHandedRender },
  /* STATE_MENU_FACTORY        */ { stMenuFactoryEnter, stMenuFactoryButton, stMenuFactoryRender },
};

static_assert(sizeof(STATES) / sizeof(STATES[0]) == STATE_COUNT,
              "STATES must have exactly one row per AppState (in enum order)");

// --------------------------------------------------------------- LOOP

bool loopState() {
  if (state == stateNext) {
    return false;
  }

  LOG("main: switching state from %d to %d\n", state, stateNext);

  uint8_t lastStart = mainNavStartLast;
  uint8_t lastSelected = mainNavSelectedLast;
  mainNavStartLast = mainNavStart;
  mainNavSelectedLast = mainNavSelected;

  if (stateNext == statePrev) {
    mainNavStart = lastStart;
    mainNavSelected = lastSelected;
  } else {
    mainNavStart = 0;
    mainNavSelected = 0;
  }

  statePrev = state;
  state = stateNext;
  oledUpdate = true;

  if (state < STATE_COUNT && STATES[state].onEnter) {
    STATES[state].onEnter();
  } else {
    LOG("main: undefined state for state switch (%d)\n", state);
  }
  return true;
}

bool loopInteraction() {
  if (dialButtonGetAndClear()) {
    LOG("Button\n");
    if (state < STATE_COUNT && STATES[state].onButton) {
      STATES[state].onButton();
    } else {
      LOG("main: undefined state for button press (%d)\n", state);
    }
    LOG("main: next (%d)\n", stateNext);
    return true;
  }

  int8_t diff = dialPositionGetRelativeAndClear();
  if (diff != 0) {
    //LOG("Change %d %d\n", diff, mainNavSelected);
    oledUpdate |= mainNavDial(diff);
    return true;
  }

  return false;
}

bool loopOled() {
  if (!oledUpdate) {
    return false;
  }
  oledUpdate = false;

  oledBufferClear();

  if (state < STATE_COUNT && STATES[state].onRender) {
    STATES[state].onRender();
  } else {
    LOG("main: undefined state for oled update selected (%d)\n", state);
  }

  oledBufferSend();
  return true;
}

void enterSleep() {
  oledEnabled(false);

  // Sleep until the encoder GPIO wakes us — the only enabled wake source
  // (configured once in dialSetup). No timed wake is needed: the display is
  // off while asleep, so there is nothing to keep current, and the system
  // clock (RTC/LP domain) keeps advancing, so timeMinutesGet() is already
  // correct on wake. Loop in case some other source ever fires spuriously.
  do {
    esp_light_sleep_start();
  } while (esp_sleep_get_wakeup_cause() != ESP_SLEEP_WAKEUP_GPIO);

  oledEnabled(true);

  dialButtonGetAndClear();
  dialPositionGetRelativeAndClear();

  oledUpdate = true;
  mainActionLast = time(NULL);
}

// --------------------------------------------------------------- ENTRY POINTS

void setup() {
  delay(500);

  LOG_BEGIN(115200);
  LOG("\n\n");
  LOG("%s %s %s\n", appName, appVersion, appRev);
  LOG("https://github.com/kiu/%s\n", appName);
  LOG("\n");

  oledSetup();

  oledShowSplash();
  delay(3000);

  wifiSetup();

  dialSetup();

  stateNext = STATE_PLACES_LIST;
}

void loop() {
  bool changed = false;
  changed |= loopState();
  changed |= loopInteraction();

  // Keep the displayed time current: the clock (RTC) advances on its own, so
  // redraw whenever the minute-of-day changes. This does not count as user
  // activity, so it never defers sleep (matching the old per-minute ISR).
  static uint32_t loopLastMinute = 0xFFFFFFFF;
  uint32_t nowMinute = timeMinutesGet();
  if (nowMinute != loopLastMinute) {
    loopLastMinute = nowMinute;
    mainOledUpdate();
  }

  loopOled();

  if (changed) {
    mainActionLast = time(NULL);
    return;
  }

#ifndef DEV_MODE
  if (SLEEP_IN_SECONDS > 0) {
    if ((time(NULL) - mainActionLast) > SLEEP_IN_SECONDS) {
      enterSleep();
      mainNetworkPlacesDownload();
    }
  }
#endif
}

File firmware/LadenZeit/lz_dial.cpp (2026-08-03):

#include "lz_dial.h"

#include <esp_sleep.h>

volatile int8_t encoderPos = 0;
volatile uint8_t encoderCodeLast = 0;

volatile bool encoderButtonPress = false;  // debounced press, consumed by dialButtonGetAndClear()
volatile unsigned long encoderButtonLastBounceTime = 0;
const unsigned long encoderButtonDebounceDelay = 25;

void IRAM_ATTR dialInterruptRotate() {
  uint8_t MSB = digitalRead(PIN_ENCODER_MSB);
  uint8_t LSB = digitalRead(PIN_ENCODER_LSB);
  uint8_t encoded = (MSB << 1) | LSB;
  uint8_t sum = (encoderCodeLast << 2) | encoded;
  encoderCodeLast = encoded;
  // The standard quadrature sequence is 00 -> 01 -> 11 -> 10 -> 00
  if (encoderPos < 127 && (sum == 0b1101 || sum == 0b0100 || sum == 0b0010 || sum == 0b1011)) encoderPos++;
  if (encoderPos > -127 && (sum == 0b1110 || sum == 0b0111 || sum == 0b0001 || sum == 0b1000)) encoderPos--;
}

// Button is active-low (pressed = LOW), attached on CHANGE so this runs on every
// edge. Edges closer together than encoderButtonDebounceDelay are contact
// chatter: keep extending the quiet window and ignore them. Once the signal has
// been quiet for the full window, a press is registered on the settled release —
// the edge at which the pin reads HIGH again. Sampling only settled HIGH levels
// (never mid-bounce) is what makes repeated clicks reliable.
void IRAM_ATTR dialInterruptButton() {
  unsigned long now = millis();

  if (now - encoderButtonLastBounceTime < encoderButtonDebounceDelay) {
    encoderButtonLastBounceTime = now;  // chatter: extend the quiet window
    return;
  }

  if (digitalRead(PIN_ENCODER_BTN) == HIGH) {  // settled release
    encoderButtonLastBounceTime = now;
    encoderButtonPress = true;
  }
}

void dialSetup() {
  pinMode(PIN_ENCODER_MSB, INPUT);
  pinMode(PIN_ENCODER_LSB, INPUT);
  pinMode(PIN_ENCODER_BTN, INPUT);

  attachInterrupt(digitalPinToInterrupt(PIN_ENCODER_MSB), dialInterruptRotate, CHANGE);
  attachInterrupt(digitalPinToInterrupt(PIN_ENCODER_LSB), dialInterruptRotate, CHANGE);
  attachInterrupt(digitalPinToInterrupt(PIN_ENCODER_BTN), dialInterruptButton, CHANGE);

  gpio_wakeup_enable((gpio_num_t)PIN_ENCODER_MSB, GPIO_INTR_LOW_LEVEL);
  gpio_wakeup_enable((gpio_num_t)PIN_ENCODER_LSB, GPIO_INTR_LOW_LEVEL);
  gpio_wakeup_enable((gpio_num_t)PIN_ENCODER_BTN, GPIO_INTR_LOW_LEVEL);

  esp_sleep_enable_gpio_wakeup();
}

bool dialButtonGetAndClear() {
  bool result = encoderButtonPress;
  encoderButtonPress = false;
  return result;
}

int8_t dialPositionGetRelativeAndClear() {
  int8_t result = encoderPos / 4;
  if (result != 0) {
    encoderPos = 0;
  }
  return result;
}
